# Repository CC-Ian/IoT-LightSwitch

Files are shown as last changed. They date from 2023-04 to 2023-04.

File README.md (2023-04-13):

# An Open Source "IoT" Lightswitch
This project seeks to implement a wifi connected, computer controlled lightswitch which protects the user's privacy, and has more features than a traditional light switch.

## DANGER! LETHAL VOLTAGES
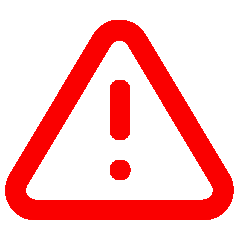
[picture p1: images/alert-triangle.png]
  
This project is not for the inexperienced. There is exposed AC Mains present on the PCB, and installation requires modifying the AC Mains Connection within a switch box.  

## FIRE HAZARD WARMING
This product is designed to switch on and off a ceiling fan and a light or two. The mains traces are rated at 6A for a 10 degree rise over ambient. Install a 5A fuse in the location on the PCB, and ensure that your load is less than 5A before using this device.

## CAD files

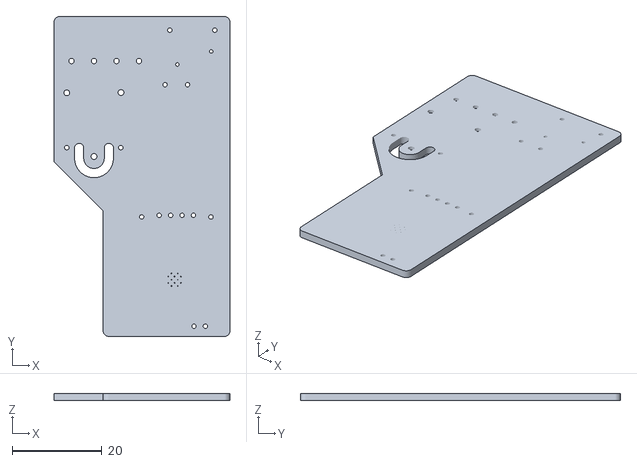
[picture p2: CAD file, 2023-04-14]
Hardware/Unnamed-IoT Lightswitch 1.stl
39.1 x 71.1 x 1.58

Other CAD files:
Hardware/IoT Lightswitch.step

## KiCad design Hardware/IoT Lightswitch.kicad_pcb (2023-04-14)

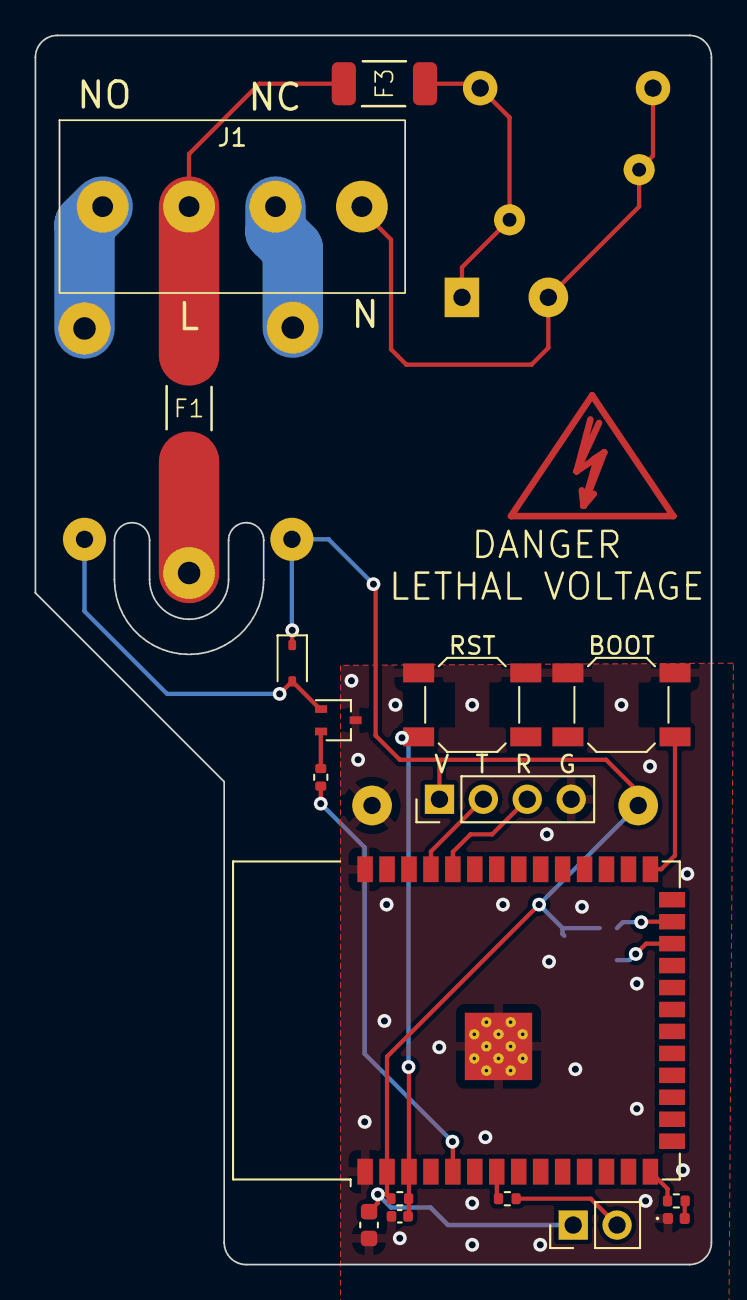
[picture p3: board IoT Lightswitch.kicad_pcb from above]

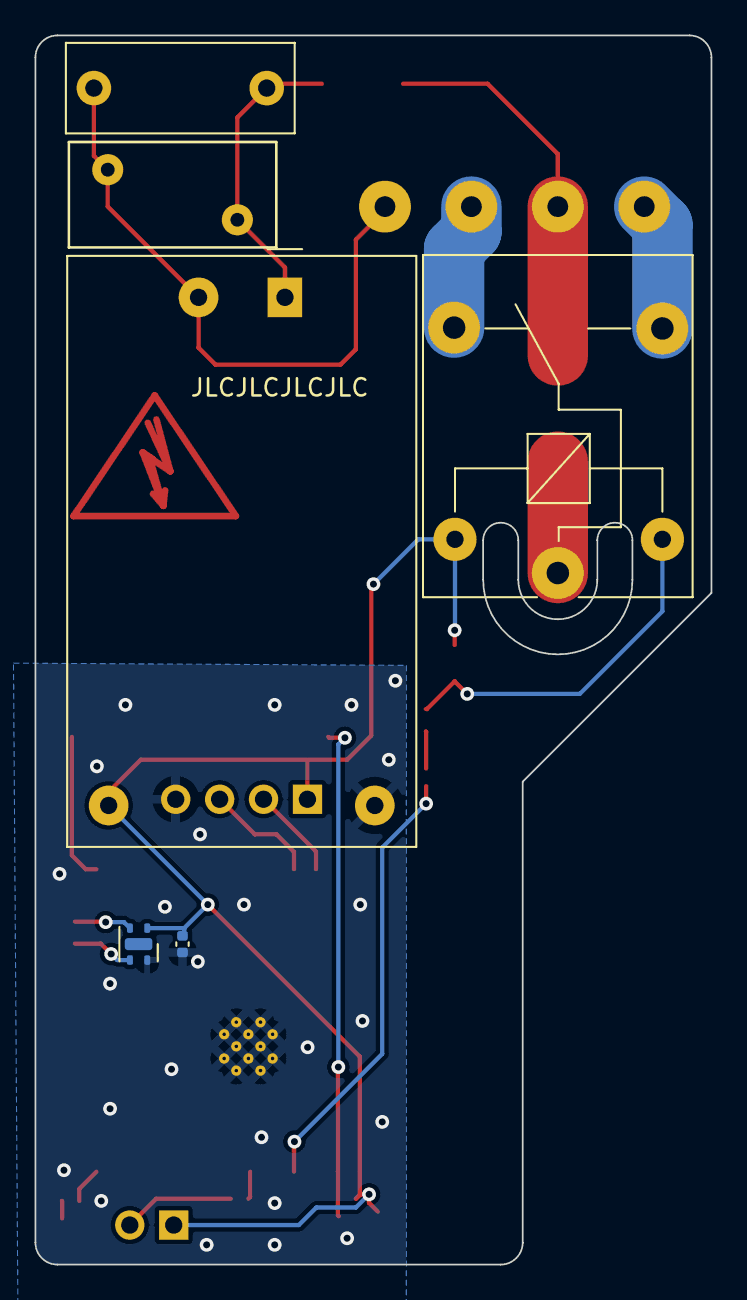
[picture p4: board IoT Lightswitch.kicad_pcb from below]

Board: 2 copper layers, 39.1 x 71.1 mm, 23 parts (6 on the bottom side), 21 nets.

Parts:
BOOT: SW_Push; SW_SPST_SKQG_WithStem
C1, C4: 100n; C_0402_1005Metric
C2: 150n; C_Rect_L13.0mm_W5.0mm_P10.00mm_FKS3_FKP3_MKS4
C3: 10u; C_0603_1608Metric
D1: D; D_SOD-323
D2: LED; LED_0402_1005Metric
F1: 5A 250v; Fuse_6125
F3: 0.5A 125v; Fuse_6125
J1: Screw_Terminal_01x04; WJ128V-5.0-2P
K1: SANYOU_SRD_Form_C; Relay_SPDT_SANYOU_SRD_Series_Form_C
PS1: HLK-PM03; Converter_ACDC_HiLink_HLK-PMxx
Q1: NMOS; SOT-323_SC-70
R1, R2, R3: 10k; R_0402_1005Metric
R4: 5k1; R_0402_1005Metric
RST: SW_Push; SW_SPST_SKQG_WithStem
RV1: Varistor; RV_Disc_D12mm_W6.1mm_P7.5mm
SW5: SW_SPST; PinHeader_1x02_P2.54mm_Vertical
U1: ESP32-S2-SOLO-2; ESP32-S3-WROOM-1
U2: SHTC3; Sensirion_DFN-4-1EP_2x2mm_P1mm_EP0.7x1.6mm
V  T  R  G: Conn_01x04; PinHeader_1x04_P2.54mm_Vertical

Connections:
+3V3: C3.1, C4.1, D1.1 (K), K1.2, PS1.4 (+Vout), R1.2, SW5.1 (A), U1.2 (VCC), U2.1 (VDD), V T R G.1
AC_L: F1.1, F3.1, J1.3
AC_L_FUSED: F1.2, K1.1
AC_N: C2.2, J1.1, PS1.2 (AC/N), RV1.2
AC_NC: J1.2, K1.4
AC_NO: J1.4, K1.3
BOOT: BOOT.2, U1.27 (IO0)
GND: BOOT.1, C1.2, C3.2, C4.2, D2.1 (K), PS1.3 (-Vout), Q1.3 (S), RST.2, U1.1 (GND), U1.40 (GND), U1.41 (EPAD), U2.4 (VSS), V T R G.4
IO5: R2.2, U1.5 (IO5)
IO7: R3.2, U1.7 (IO7)
IO20: R4.2, U1.14 (IO20)
unnamed: D1.2 (A), K1.5, Q1.1 (D)
unnamed: D2.2 (A), R4.1
unnamed: C2.1, F3.2, PS1.1 (AC/L), RV1.1
unnamed: Q1.2 (G), R2.1
unnamed: R3.1, SW5.2 (B)
RST: C1.1, R1.1, RST.1, U1.3 (EN)
RX: U1.36 (RX), V T R G.3
SCL: U1.25 (IO34), U2.2 (SCL)
SDA: U1.24 (IO33), U2.3 (SDA)
TX: U1.37 (TX), V T R G.2

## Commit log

2023-04-13 Updated Schema
    [IoT Lightswitch.kicad_sch]
2023-04-13 Moved PSU Fuse from Neutral to Live
    [IoT Lightswitch-B_Cu.gbr, IoT Lightswitch-B_Mask.gbr, IoT Lightswitch-B_Paste.gbr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]
2023-04-14 Added Humidity and Temperature Sensor
    [IoT Lightswitch.kicad_pcb, IoT Lightswitch.kicad_sch, IoT Lightswitch.step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]
